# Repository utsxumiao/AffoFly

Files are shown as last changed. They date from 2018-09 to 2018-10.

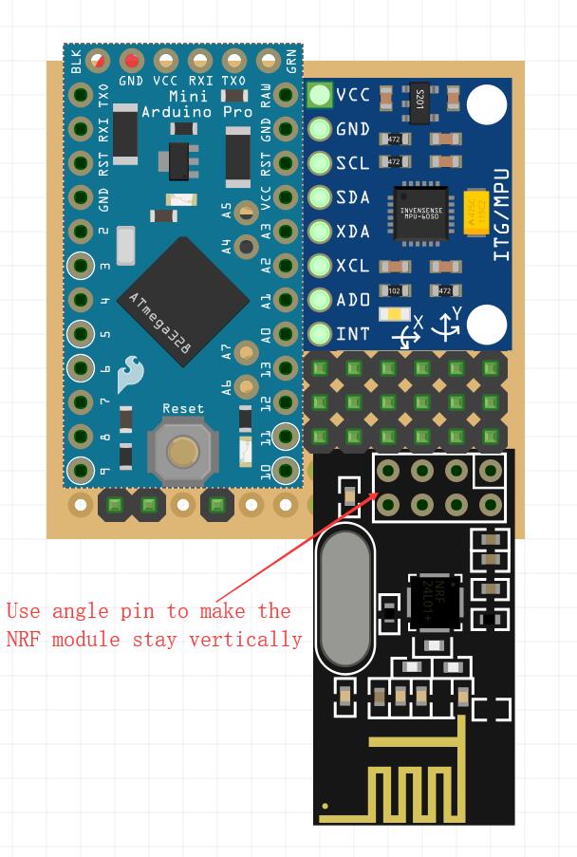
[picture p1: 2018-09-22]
Content/Images/AffoFly_MultiWii_Board_Layout_02.jpg

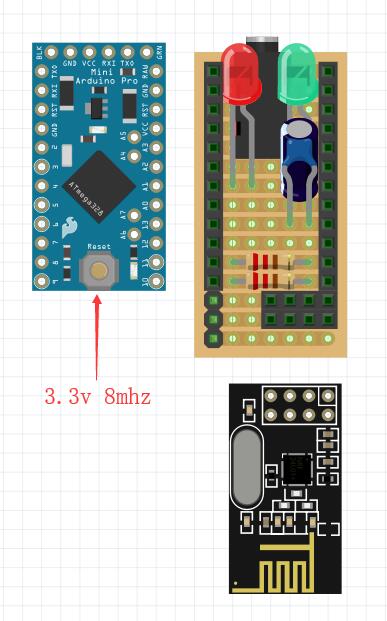
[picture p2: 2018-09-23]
Content/Images/AffoFly_Receiver_Board_Layout_01.jpg

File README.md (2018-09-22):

# AffoFly
Affordable Drone Project

### Warning
This software is experimental and a work in progress, it is partially developed at the moment and has not been tested in field yet. Code should be only used for reference until I feel comfortable to make it as a release version. DRONE CAN BE VERY DANGEROUS SO REMOVE YOUR PROPELLER!

THE SOFTWARE IS PROVIDED "AS IS", WITHOUT WARRANTY OF ANY KIND, EXPRESS OR IMPLIED, INCLUDING BUT NOT LIMITED TO THE WARRANTIES OF MERCHANTABILITY, FITNESS FOR A PARTICULAR PURPOSE AND NONINFRINGEMENT. IN NO EVENT SHALL THE AUTHORS OR COPYRIGHT HOLDERS BE LIABLE FOR ANY CLAIM, DAMAGES OR OTHER LIABILITY, WHETHER IN AN ACTION OF CONTRACT, TORT OR OTHERWISE, ARISING FROM, OUT OF OR IN CONNECTION WITH THE SOFTWARE OR THE USE OR OTHER DEALINGS IN THE SOFTWARE.

### What Is This Project About?
This is a complete **LOW COST** guide for DIY Arduino and NRF2401+ based drone package which includes: 
- Transmitter(TX): [AffoFly_Transmitter](/AffoFly_Transmitter)
- Receiver(RX): [AffoFly_Receiver](/AffoFly_Receiver)
- Flight Controller(FC): [AffoFly_MultiWii](/AffoFly_MultiWii)
- [Frame](/frame) (the body of drone) 
- [Other Parts](/other-parts) Brushless motors, Escs, batteries, propellers and so forth.

### The Motivation
I've been in RC hobby for about three years so far, mainly on building and flying drones and some glider planes. I've been seeing friends, neighbours, and sometimes, boys in the park shown great interest about DIY RC hobby, most of them played toy drones and wanna go deeper into DIY. Then they are scared away or stepped back after asking how much it will cost to enter DIY RC world (they actually meant the whole set to fly), a basic radio transmitter/receiver set already cost at least $50 as least. 

Products on shelf are normally over priced in Australia IMO and only good for urgent needs or "other good reasons", understandablly, labour and shipping cost is quite high here and the tiny market makes the case even worse, vendors only stock high value (of course better quality and better performance) items in order to maintain an acceptable margin. I do not against high end products as I do own some decent drone parts, transmitters and have been spending thousands over these years but that is not the topic of this project.

I was wondering if there is any way to let those guys try out in the pool before jumping into the ocean. Until recently I dive into [MultiWii](https://github.com/multiwii) and [Arduino](https://www.arduino.cc), I realised that it is absolutely possible to build the whole lot within $50 and they are hobby grade rather than just a ready made toy.

### The Goal
The aim of this project is mainly for people want try out DIY RC Drone without making too much damage to their bank account, ultimately get your DIY drone in the air under **$50**(USD). Also for learning purposes I would like to learn together on hardware and C/C++ programming as I am new to this as well. We are not going to reinvention the wheel if any aspect of this project has been done by someone, we are here to put them in use and improve it if possible.

### Prerequisites
To build a drone by following this project DOES NOT require expirence of software programming, just some simple configuration by instruction then upload the sketch onto your board and it should work, of course you do need to do some soldering work and some tools like soldering iron for those electronics parts and some handy work on the drone frame. 

### Welcome
If you would like to learn Arduino development, let's learn together! If you are a C/C++ programmer, it would be really appreciated if you can comment/help on improving this project, especially on my newbie's sketches. (I am a .NET developer have no background of hardware (C/C++) programming at all, sketches in this project are "working" but I am pretty sure there are many places could be better, eg. data types, workflows on handling loops...)

### Side Notes
 - **Radio Frequency**. The NRF24L01+ module provides 126 channels (0 - 125) mapping frequencies from 2400mhz to 2525mhz respectively, if you are planning to use it in areas close to residential like even indoor (a lot of WIFI) better stick to channels from 85 (2485mhz) and above to minimize interference, it gives you 40 channels to choose from, for simplicity I prefer starts from 100 and 25 channels is plenty for me. According to [List of WLAN channels](https://en.wikipedia.org/wiki/List_of_WLAN_channels) most WIFI routers are using frenquency under 2484mhz.

### Acknowlegements
- [MultiWii Community](http://www.multiwii.com)
- [Arduino](https://www.arduino.cc)
- [iforce2d](https://www.youtube.com/channel/UCTXOorupCLqqQifs2jbz7rQ). He has heaps of interesting, informative and yet good quality videos.

### Licensing
[MIT License](/LICENSE)

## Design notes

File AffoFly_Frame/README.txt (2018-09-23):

Here should contain all kinds of frame build, one frame per directory.

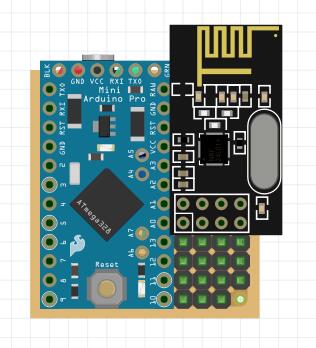
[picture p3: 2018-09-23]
Content/Images/AffoFly_Receiver_Board_Layout_04.jpg

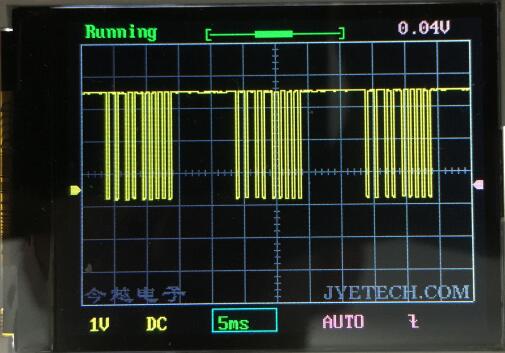
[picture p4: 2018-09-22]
Content/Images/Flysky_I6_PPM_5ms.jpg

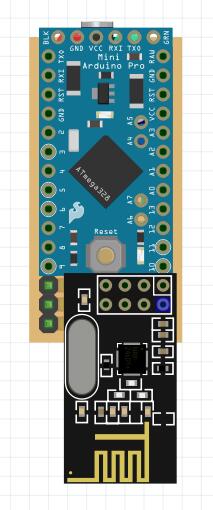
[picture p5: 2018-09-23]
Content/Images/AffoFly_Receiver_Board_Layout_02.jpg

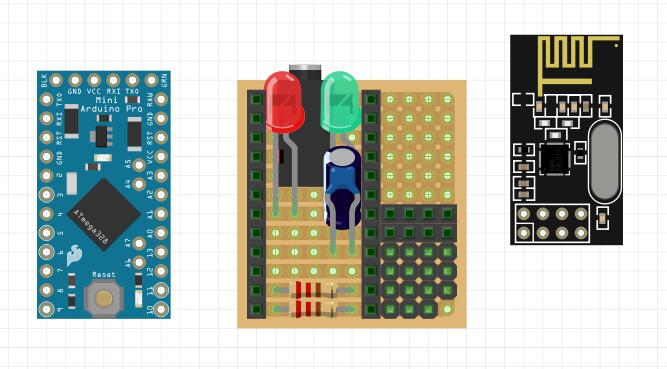
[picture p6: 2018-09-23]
Content/Images/AffoFly_Receiver_Board_Layout_03.jpg

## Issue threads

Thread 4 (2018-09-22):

Make TX output PPM signal for flight simulator

utsxumiao, 2018-09-22:
Currently I run out of PINs on TX Arduino.

Joysticks => A0, A1, A2, A3
Screen    => A4, A5
Battery   => A6
Dail (Aux6) => A7
Aux1-Aux5 buttons => 2, 3, 4, 5, 6
NRF24    => 7, 8, 11, 12, 13
Buzzer    => 9
Menu button => 10

I am wondering if I can use a pin currently for NRF module, keep NRF module connected but just not run radio function when TX is in simulator mode...... Need some investigation and tests.

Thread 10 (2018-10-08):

Button trigger multiple times in Control mode

utsxumiao, 2018-10-08:
This is something wrong in Control mode, when press buttons it triggers multiple times. This only happens in Control mode but working well in Function mode.

Not sure what is the cause but Arduino Studio does give low memory warning, code needs to be refactored to shrink size and improve performance.

utsxumiao, 2018-10-08:
Fixed in commit ffd4ae650dcb241efc1d0839de9541dfe30fbb60

Closed 2018-10-08.

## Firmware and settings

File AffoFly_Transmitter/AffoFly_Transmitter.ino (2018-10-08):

#include <EEPROM.h>
#include <SPI.h>
#include <Wire.h>
#include <nRF24L01.h>
#include <RF24.h>
#include <Bounce2.h>
#include <U8g2lib.h>
#include "printf.h"

//==== System Setting =============================================//
#define VERSION_NUMBER     "0.013"
//#define DEBUG_MODE  1
#define SHOW_RATE   1
//=======================================================================//

//==== Pin Definition ===================================================//
// PIN A4, A5 are used as I2C to connect LCD screen
// Pin 11, 12, 13 are used as SPI to connect NRF module
// Becareful: when use A6, A7 pin
//      A6, A7 are analog input only, also have no internal pullup.
//      You will need to add external pullup/pulldown resistor for them.
#define THROTTLE_PIN  A0
#define YAW_PIN       A1
#define PITCH_PIN     A2
#define ROLL_PIN      A3
#define V_BATTERY_PIN A6
#define AUX6_PIN      A7  //SWD
#define AUX1_PIN      2   //Arm - 2 states (bool)                                             //Menu: Save
#define AUX2_PIN      3   //Flight Mode - 3 states but could be more (byte: Acro/Angle/...)   //Menu: Up
#define AUX3_PIN      4   //Bomb Drop - 2 states (bool)                                       //Menu: Down
#define AUX4_PIN      5   //Beacon - 2 state (bool)                                           
#define AUX5_PIN      6   //
#define NRF_CE_PIN    7
#define NRF_CSN_PIN   8
#define BUZZER_PIN    9   //OUTPUT                                                            
#define MENU_PIN      10
//=======================================================================//

//==== Global Constant & Variable =======================================//
uint16_t BatteryVoltage = 0;
uint16_t LowBatteryVoltageThreshold = 3400; // mV

#ifdef SHOW_RATE
uint8_t SendRate = 0;
uint16_t LoopRate = 0;
uint8_t SendCount = 0;
uint16_t LoopCount = 0;
#endif

bool FunctionMode = false;
bool TrimmingMode = false;

const uint8_t RADIO_UNIQUE_ID_EEPROM_ADDRESS = 0; //(2 bytes 0-1)
const uint16_t RADIO_UNIQUE_ID_LOWER_BOUNDARY = 1000;
const uint16_t RADIO_UNIQUE_ID_UPPER_BOUNDARY = 9999;
uint16_t RadioUniqueId = RADIO_UNIQUE_ID_LOWER_BOUNDARY;

const uint8_t RADIO_PA_LEVEL_INDEX_EEPROM_ADDRESS = 4;
const uint8_t RADIO_PA_LEVEL_INDEX_LOWER_BOUNDARY = 0; //RF24_PA_MIN, RF24_PA_LOW, RF24_PA_HIGH, RF24_PA_MAX
const uint8_t RADIO_PA_LEVEL_INDEX_UPPER_BOUNDARY = 3; //TODO: use index instead
int8_t RadioPaLevelIndex = 3;

const uint8_t CURRENT_RX_ID_EEPROM_ADDRESS = 5; //TODO: Implement Multiple RX support
const uint8_t CURRENT_RX_ID_LOWER_BOUNDARY = 1;
const uint8_t CURRENT_RX_ID_UPPER_BOUNDARY = 10;
uint8_t CurrentRxId = 1;

const uint8_t RX_CONFIG_EEPROM_START_ADDRESS = 100;
const uint8_t RX_CONFIG_ALLOCATED_BYTES = 20;
const uint8_t RX_TRIM_STEP_RANGE = 15;
const uint8_t RX_TRIM_STEP_WIDTH = 2;

const uint8_t RADIO_CHANNEL_LOWER_BOUNDARY = 100;
const uint8_t RADIO_CHANNEL_UPPER_BOUNDARY = 125;
const uint64_t RADIO_PIPE_OUT = 0xE8E8F0F0E1LL;
RF24 radio(NRF_CE_PIN, NRF_CSN_PIN);

U8G2_SSD1306_128X64_NONAME_2_HW_I2C u8g2(U8G2_R0, /* clock=*/ SCL, /* data=*/ SDA, /* reset=*/ U8X8_PIN_NONE);

const uint8_t AUX1_VALUE_LOWER_BOUNDARY = 0;
const uint8_t AUX1_VALUE_UPPER_BOUNDARY = 1;
uint8_t Aux1Value = AUX1_VALUE_LOWER_BOUNDARY;
Bounce Aux1Bounce = Bounce();
bool Aux1Pressed = false;
const uint8_t AUX2_VALUE_LOWER_BOUNDARY = 0;
const uint8_t AUX2_VALUE_UPPER_BOUNDARY = 2;
uint8_t Aux2Value = AUX2_VALUE_LOWER_BOUNDARY;
Bounce Aux2Bounce = Bounce();
bool Aux2Pressed = false;
const uint8_t AUX3_VALUE_LOWER_BOUNDARY = 0;
const uint8_t AUX3_VALUE_UPPER_BOUNDARY = 1;
uint8_t Aux3Value = AUX3_VALUE_LOWER_BOUNDARY;
Bounce Aux3Bounce = Bounce();
bool Aux3Pressed = false;
const uint8_t AUX4_VALUE_LOWER_BOUNDARY = 0;
const uint8_t AUX4_VALUE_UPPER_BOUNDARY = 1;
uint8_t Aux4Value = AUX4_VALUE_LOWER_BOUNDARY;
Bounce Aux4Bounce = Bounce();
bool Aux4Pressed = false;
const uint8_t AUX5_VALUE_LOWER_BOUNDARY = 0;
const uint8_t AUX5_VALUE_UPPER_BOUNDARY = 3;
uint8_t Aux5Value = AUX5_VALUE_LOWER_BOUNDARY;
Bounce Aux5Bounce = Bounce();
bool Aux5Pressed = false;

Bounce MenuBounce = Bounce();
bool MenuPressed = false;

// NRF24L01+ module can send maximum 32 byte per package
struct MyData {
  uint16_t UniqueId;
  uint16_t Throttle;
  uint16_t Yaw;
  uint16_t Pitch;
  uint16_t Roll;
  uint16_t Aux1;
  uint16_t Aux2;
  uint16_t Aux3;
  uint16_t Aux4;
  uint16_t Aux5;
  uint16_t Aux6;
};
MyData data;

const uint16_t BatteryVoltageReadInterval = 10000;
unsigned long BatteryVoltageReadLastMillis = 0;

const uint16_t FunctionWelcomeScreenShowDuration = 2000;

const uint16_t TimerRefreshInterval = 1000;
unsigned long TimerRefreshLastMillis = 0;
uint16_t Timer_Seconds = 0;

uint16_t ScreenRefreshInterval = 500;
unsigned long ScreenRefreshLastMillis = 0;

bool BuzzerEnabled = false;
uint8_t BuzzerTimesToBeep = 0;
byte BuzzerState = LOW;
uint16_t BuzzerBeepInterval = 50;
unsigned long BuzzerBeepLastMillis = 0;

const uint8_t RadioSendInterval = 10;
unsigned long RadioSendLastMillis = 0;

char FlightMode[3][10] = {
  "ACRO",
  "ANGLE",
  "HORIZON"
};

// RxConfig data limit is 20 bytes
// We allocates 10 RxConfig in EEPROM from address 100 to 299
struct RxConfigData {
  uint8_t Id;
  uint8_t RadioChannel;
  int8_t ThrottleTrim;
  int8_t YawTrim;
  int8_t PitchTrim;
  int8_t RollTrim;
  char Name[10];
};

RxConfigData rxConfig;
RxConfigData RxConfigs[10];

struct RadioPaLevelData {
  uint8_t PaValue;
  char PaName[5];
};

RadioPaLevelData RadioPaLevels[4] = {
  {RF24_PA_MIN, "MIN"},
  {RF24_PA_LOW, "LOW"},
  {RF24_PA_HIGH, "HIGH"},
  {RF24_PA_MAX, "MAX"}
};

char Functions[4][15] = {
  "Transmitter ID",
  "Radio PA Level",
  "RX Selection",
  "Wipe All Data"
};

uint8_t CurrentTrimmingIndex = 0; // 0=>Yaw, 1=>Throttle, 2=>Pitch, 3=>Roll
uint8_t CurrentFunctionIndex = 0;
uint8_t SelectedFunctionIndex = 1;
uint8_t SelectedRxId = CurrentRxId;
uint8_t RxConfigurationIndex = 0;
uint8_t RxConfigurationNameIndex = 0;
char RxConfigurationName[10] = "";
uint8_t RxConfigurationChannel = 100;

//=======================================================================//

void setup() {
#ifdef DEBUG_MODE
  Serial.begin(115200);
#endif
  u8g2.begin();
  u8g2.setFont(u8g2_font_profont12_tr);
  readEeprom();
  pinMode(AUX1_PIN, INPUT_PULLUP);
  pinMode(AUX2_PIN, INPUT_PULLUP);
  pinMode(AUX3_PIN, INPUT_PULLUP);
  pinMode(AUX4_PIN, INPUT_PULLUP);
  pinMode(AUX5_PIN, INPUT_PULLUP);
  pinMode(MENU_PIN, INPUT_PULLUP);
  pinMode(BUZZER_PIN, OUTPUT);

  Aux1Bounce.attach(AUX1_PIN);
  Aux2Bounce.attach(AUX2_PIN);
  Aux3Bounce.attach(AUX3_PIN);
  Aux4Bounce.attach(AUX4_PIN);
  Aux5Bounce.attach(AUX5_PIN);
  MenuBounce.attach(MENU_PIN);
  Aux1Bounce.interval(5);
  Aux2Bounce.interval(5);
  Aux3Bounce.interval(5);
  Aux4Bounce.interval(5);
  Aux5Bounce.interval(5);
  MenuBounce.interval(5);

  MenuBounce.update();
  if (MenuBounce.read() == LOW) {
    FunctionMode = true;
    ScreenRefreshInterval = 200;
    BuzzerTimesToBeep = 3;
  } else {
    FunctionMode = false;
    BuzzerTimesToBeep = 1;
  }

  // Seed RxConfigs if it does not already exist
  if (EEPROM.read(RX_CONFIG_EEPROM_START_ADDRESS) == 0) {
#ifdef DEBUG_MODE
    Serial.println("RX data does not exist, seed data.");
#endif
    putRxConfigs();
  }

  //FunctionMode = true; //For testing only, remove after.

  if (FunctionMode) {
    drawFunctionWelcomeScreen();
    getRxConfigs();
#ifdef DEBUG_MODE
    dumpEeprom();
#endif
  } else {
    rxConfig = getRxConfig(CurrentRxId);
    radio.begin();
    radio.setPALevel(RadioPaLevels[RadioPaLevelIndex].PaValue);
    radio.setAutoAck(false);
    radio.setChannel(rxConfig.RadioChannel);
    radio.setDataRate(RF24_250KBPS);
    radio.openWritingPipe(RADIO_PIPE_OUT);
    radio.startListening();
    radio.stopListening();
#ifdef DEBUG_MODE
    printf_begin();
    radio.printDetails();
    Serial.print("UniqueId "); Serial.print(RadioUniqueId);
    Serial.print("    Channel "); Serial.println(rxConfig.RadioChannel);
#endif
  }
  resetData();
  readBatteryVoltage(10001); //Dummy value > BatteryVoltageReadInterval to force battery read once
}

void loop() {
  unsigned long currentMillis = millis();
  if (FunctionMode) {
    if (currentMillis > FunctionWelcomeScreenShowDuration) {
      setTime(currentMillis);
      setFunctionValues();
      beepBuzzer(currentMillis);
      refreshFunctionOperationScreen(currentMillis);
    }
  } else {
    readBatteryVoltage(currentMillis);
    setTime(currentMillis);
    setButtonsValue(currentMillis);
    beepBuzzer(currentMillis);
    sendPayloadData(currentMillis);
    refreshControlScreen(currentMillis);
  }
#ifdef SHOW_RATE
  LoopCount++;
#endif
}

void readEeprom() {
  EEPROM.get(RADIO_UNIQUE_ID_EEPROM_ADDRESS, RadioUniqueId);
  if (RadioUniqueId < RADIO_UNIQUE_ID_LOWER_BOUNDARY || RadioUniqueId > RADIO_UNIQUE_ID_UPPER_BOUNDARY) {
    RadioUniqueId = RADIO_UNIQUE_ID_LOWER_BOUNDARY;
    EEPROM.write(RADIO_UNIQUE_ID_EEPROM_ADDRESS, RadioUniqueId);
  }

  RadioPaLevelIndex = EEPROM.read(RADIO_PA_LEVEL_INDEX_EEPROM_ADDRESS);
  if (RadioPaLevelIndex < RADIO_PA_LEVEL_INDEX_LOWER_BOUNDARY || RadioPaLevelIndex > RADIO_PA_LEVEL_INDEX_UPPER_BOUNDARY) {
    RadioPaLevelIndex = RADIO_PA_LEVEL_INDEX_UPPER_BOUNDARY;
    EEPROM.write(RADIO_PA_LEVEL_INDEX_EEPROM_ADDRESS, RadioPaLevelIndex);
  }

  CurrentRxId = EEPROM.read(CURRENT_RX_ID_EEPROM_ADDRESS);
  if (CurrentRxId < CURRENT_RX_ID_LOWER_BOUNDARY || CurrentRxId > CURRENT_RX_ID_UPPER_BOUNDARY) {
    CurrentRxId = CURRENT_RX_ID_LOWER_BOUNDARY;
    EEPROM.write(CURRENT_RX_ID_EEPROM_ADDRESS, CurrentRxId);
  }
}

void putRxConfigs() {
  for (int i = CURRENT_RX_ID_LOWER_BOUNDARY; i <= CURRENT_RX_ID_UPPER_BOUNDARY; i++) {
    uint16_t startAddress = (uint16_t)RX_CONFIG_ALLOCATED_BYTES * (i - 1) + RX_CONFIG_EEPROM_START_ADDRESS;
    RxConfigData rxConfig;
    rxConfig.Id = i;
    rxConfig.RadioChannel = 100;
    rxConfig.ThrottleTrim = 0;
    rxConfig.YawTrim = 0;
    rxConfig.PitchTrim = 0;
    rxConfig.RollTrim = 0;
    char rxName[10] = "RX ";
    char rxIdText[3] = "";
    itoa(i, rxIdText, 10);
    if (i < 10) {
      strcat(rxName, "0");
    }
    strcat(rxName, rxIdText);
    strcat(rxName, "    ");
    strcpy(rxConfig.Name, rxName);
    EEPROM.put(startAddress, rxConfig);
  }
}

void getRxConfigs() {
  for (int i = CURRENT_RX_ID_LOWER_BOUNDARY; i <= CURRENT_RX_ID_UPPER_BOUNDARY; i++) {
    uint16_t startAddress = (uint16_t)RX_CONFIG_ALLOCATED_BYTES * (i - 1) + RX_CONFIG_EEPROM_START_ADDRESS;
    RxConfigData rxConfig;
    EEPROM.get(startAddress, rxConfig);
    RxConfigs[i - 1] = rxConfig;
  }
}

RxConfigData getRxConfig(uint8_t rxId) {
  uint16_t address = (uint16_t)RX_CONFIG_ALLOCATED_BYTES * (rxId - 1) + RX_CONFIG_EEPROM_START_ADDRESS;
  RxConfigData rxConfig;
  EEPROM.get(address, rxConfig);
  return rxConfig;
}

void clearEeprom() {
  for (int i = 0 ; i < EEPROM.length() ; i++) {
    EEPROM.update(i, 0);
  }
  softReset();
}

void setFunctionValues() {
  Aux1Bounce.update();
  Aux2Bounce.update();
  Aux3Bounce.update();
  Aux4Bounce.update();
  Aux5Bounce.update();
  MenuBounce.update();
  int pressedButtonIndex = -1;

  if (MenuBounce.read() == LOW) {
    if (!MenuPressed) {
      MenuPressed = true;
      pressedButtonIndex = 0;
      BuzzerTimesToBeep = 1;
    }
  } else {
    MenuPressed = false;
  }
  if (Aux1Bounce.read() == LOW) {
    if (!Aux1Pressed) {
      Aux1Pressed = true;
      pressedButtonIndex = 2;
      BuzzerTimesToBeep = 1;
    }
  } else {
    Aux1Pressed = false;
  }
  if (Aux4Bounce.read() == LOW) {
    if (!Aux4Pressed) {
      Aux4Pressed = true;
      pressedButtonIndex = 1;
      BuzzerTimesToBeep = 1;
    }
  } else {
    Aux4Pressed = false;
  }
  if (Aux5Bounce.read() == LOW) {
    if (!Aux5Pressed) {
      Aux5Pressed = true;
      pressedButtonIndex = 3;
      BuzzerTimesToBeep = 1;
    }
  } else {
    Aux5Pressed = false;
  }
  if (Aux3Bounce.read() == LOW) {
    if (!Aux3Pressed) {
      Aux3Pressed = true;
      pressedButtonIndex = 4;
      BuzzerTimesToBeep = 1;
    }
  } else {
    Aux3Pressed = false;
  }

  if (pressedButtonIndex > -1) {
    if (CurrentFunctionIndex == 0) {
      //Currently at Main Menu
      switch (pressedButtonIndex) {
        case 0: //Cancel
          break;
        case 1: //Confirm
          CurrentFunctionIndex = SelectedFunctionIndex;
          readEeprom();
          break;
        case 2: //Up
          SelectedFunctionIndex--;
          break;
        case 3: //Down
          SelectedFunctionIndex++;
          break;
      }
      uint8_t functionCount = sizeof(Functions) / sizeof(Functions[0]);
      if (SelectedFunctionIndex > functionCount) SelectedFunctionIndex = 1;
      if (SelectedFunctionIndex < 1) SelectedFunctionIndex = functionCount;
    }
    else if (CurrentFunctionIndex == 1) {
      //Currently at Transmitter Id function
      switch (pressedButtonIndex) {
        case 0: //Cancel
          CurrentFunctionIndex = 0;
          break;
        case 1: //Confirm
          EEPROM.put(RADIO_UNIQUE_ID_EEPROM_ADDRESS, RadioUniqueId);
          break;
        case 2: //Up
          RadioUniqueId++;
          break;
        case 3: //Down
          RadioUniqueId--;
          break;
          //case 4: //Move Position TODO: make it easier to change value by each digit
      }
      if (RadioUniqueId < RADIO_UNIQUE_ID_LOWER_BOUNDARY) RadioUniqueId = RADIO_UNIQUE_ID_UPPER_BOUNDARY;
      if (RadioUniqueId > RADIO_UNIQUE_ID_UPPER_BOUNDARY) RadioUniqueId = RADIO_UNIQUE_ID_LOWER_BOUNDARY;
    }
    else if (CurrentFunctionIndex == 2) {
      //Currently at Radio PA Level function
      switch (pressedButtonIndex) {
        case 0: //Cancel
          CurrentFunctionIndex = 0;
          break;
        case 1: //Confirm
          EEPROM.update(RADIO_PA_LEVEL_INDEX_EEPROM_ADDRESS, RadioPaLevelIndex);
          break;
        case 2: //Up
          RadioPaLevelIndex++;
          break;
        case 3: //Down
          RadioPaLevelIndex--;
          break;
      }
      if (RadioPaLevelIndex < RADIO_PA_LEVEL_INDEX_LOWER_BOUNDARY) RadioPaLevelIndex = RADIO_PA_LEVEL_INDEX_UPPER_BOUNDARY;
      if (RadioPaLevelIndex > RADIO_PA_LEVEL_INDEX_UPPER_BOUNDARY) RadioPaLevelIndex = RADIO_PA_LEVEL_INDEX_LOWER_BOUNDARY;
    }
    else if (CurrentFunctionIndex == 3) {
      //Currently at RX Selection function
      switch (pressedButtonIndex) {
        case 0: //Cancel
          SelectedRxId = CurrentRxId;
          CurrentFunctionIndex = 0;
          break;
        case 1: //Confirm
#ifdef DEBUG_MODE
          Serial.print("SelectedRxId: "); Serial.println(SelectedRxId);
#endif
          CurrentRxId = SelectedRxId;
          EEPROM.update(CURRENT_RX_ID_EEPROM_ADDRESS, CurrentRxId);
          strcpy(RxConfigurationName, RxConfigs[CurrentRxId - 1].Name);
          RxConfigurationChannel = RxConfigs[CurrentRxId - 1].RadioChannel;
          RxConfigurationIndex = 0;
          RxConfigurationNameIndex = 0;
          CurrentFunctionIndex = 10; // 10 for RX Configuration function
          break;
        case 2: //Up
          SelectedRxId--;
          break;
        case 3: //Down
          SelectedRxId++;
          break;
      }
      if (SelectedRxId < CURRENT_RX_ID_LOWER_BOUNDARY) SelectedRxId = CURRENT_RX_ID_UPPER_BOUNDARY;
      if (SelectedRxId > CURRENT_RX_ID_UPPER_BOUNDARY) SelectedRxId = CURRENT_RX_ID_LOWER_BOUNDARY;
    }
    else if (CurrentFunctionIndex == 4) {
      //Currently at Wipe All Data function
      switch (pressedButtonIndex) {
        case 0: //Cancel
          CurrentFunctionIndex = 0;
          break;
        case 1: //Confirm
          clearEeprom();
          break;
      }
    }
    else if (CurrentFunctionIndex == 10) {
      //Currently at RX Configuration function
      switch (pressedButtonIndex) {
        case 0: //Cancel
          CurrentFunctionIndex = 0;
          break;
        case 1: //Confirm
          strcpy(RxConfigs[CurrentRxId - 1].Name, RxConfigurationName);
          RxConfigs[CurrentRxId - 1].RadioChannel = RxConfigurationChannel;
          EEPROM.put(RX_CONFIG_EEPROM_START_ADDRESS + (CurrentRxId - 1) * RX_CONFIG_ALLOCATED_BYTES, RxConfigs[CurrentRxId - 1]);
          break;
        case 2: //Up
          switch (RxConfigurationIndex) {
            case 0: //RX Name
              RxConfigurationName[RxConfigurationNameIndex] -= 1;
              if (RxConfigurationName[RxConfigurationNameIndex] < 32) RxConfigurationName[RxConfigurationNameIndex] = 126;
              break;
            case 1: //RX Channel
              RxConfigurationChannel++;
              if (RxConfigurationChannel > RADIO_CHANNEL_UPPER_BOUNDARY) RxConfigurationChannel = RADIO_CHANNEL_LOWER_BOUNDARY;
          }
          break;
        case 3: //Down
          switch (RxConfigurationIndex) {
            case 0: //RX Name
#ifdef DEBUG_MODE
              Serial.println(RxConfigurationName);
#endif
              RxConfigurationName[RxConfigurationNameIndex] += 1;
              if (RxConfigurationName[RxConfigurationNameIndex] > 126) RxConfigurationName[RxConfigurationNameIndex] = 32;
#ifdef DEBUG_MODE
              Serial.println(RxConfigurationName);
#endif
              break;
            case 1: //RX Channel
              RxConfigurationChannel--;
              if (RxConfigurationChannel < RADIO_CHANNEL_LOWER_BOUNDARY) RxConfigurationChannel = RADIO_CHANNEL_UPPER_BOUNDARY;
          }
          break;
        case 4: //Move Position
          if (RxConfigurationIndex == 0) {
            RxConfigurationNameIndex++;
            if (RxConfigurationNameIndex > 8) { //TODO: Make it globle variable
              RxConfigurationNameIndex = 0;
              RxConfigurationIndex = 1;
            }
          } else {
            RxConfigurationIndex = 0;
          }
          break;
      }
    }
    else {
      //Other function
    }
  }
}

void setTime(unsigned long currentMillis) {
  if (currentMillis - TimerRefreshLastMillis >= TimerRefreshInterval) {
    TimerRefreshLastMillis = currentMillis;
    if (Aux1Value > 0)
      Timer_Seconds++;
    else
      Timer_Seconds = 0;
#ifdef SHOW_RATE
    SendRate = SendCount;
    LoopRate = LoopCount;
    SendCount = 0;
    LoopCount = 0;
#endif
  }
}

void resetData() {
  //Value 1000 - 2000, 1500 is middle/neutral
  data.Throttle = 1000;
  data.Yaw = 1500;
  data.Pitch = 1500;
  data.Roll = 1500;
  data.Aux1 = 1000;
  data.Aux2 = 1000;
  data.Aux3 = 1000;
  data.Aux4 = 1000;
  data.Aux5 = 1000;
  data.Aux6 = 1000;
}

uint16_t mapJoystickValues(uint16_t val, uint16_t lower, uint16_t middle, uint16_t upper, bool reverse) {
  val = constrain(val, lower, upper);
  if (val < middle) val = map(val, lower, middle, 1000, 1500);
  else val = map(val, middle, upper, 1500, 2000);
  return reverse ? 3000 - val : val;
}

void setButtonsValue(unsigned long currentMillis) {
  Aux1Bounce.update();
  Aux2Bounce.update();
  Aux3Bounce.update();
  Aux4Bounce.update();
  Aux5Bounce.update();
  MenuBounce.update();

  if (Aux1Bounce.read() == LOW) {
    if (!Aux1Pressed) {
      if (TrimmingMode) {
#ifdef DEBUG_MODE
        Serial.println("Current RX config data: ");
        Serial.print("Id=>");
        Serial.print(rxConfig.Id);
        Serial.print("  Name=>");
        Serial.print(rxConfig.Name);
        Serial.print("  RadioChannel=>");
        Serial.print(rxConfig.RadioChannel);
        Serial.print("  YawTrim=>");
        Serial.print(rxConfig.YawTrim);
        Serial.print("  ThrottleTrim=>");
        Serial.print(rxConfig.ThrottleTrim);
        Serial.print("  PitchTrim=>");
        Serial.print(rxConfig.PitchTrim);
        Serial.print("  RollTrim=>");
        Serial.print(rxConfig.RollTrim);
        Serial.println("");
#endif
        switch (CurrentTrimmingIndex) {
          case 0: //Yaw
            rxConfig.YawTrim++;
            if (rxConfig.YawTrim > RX_TRIM_STEP_RANGE) {
              rxConfig.YawTrim = RX_TRIM_STEP_RANGE;
            }
            if (rxConfig.YawTrim == 0) BuzzerTimesToBeep = 3;
            else BuzzerTimesToBeep = 1;
            break;
          case 1: //Throttle
            rxConfig.ThrottleTrim++;
            if (rxConfig.ThrottleTrim >= RX_TRIM_STEP_RANGE) {
              rxConfig.ThrottleTrim = RX_TRIM_STEP_RANGE;
            }
            if (rxConfig.ThrottleTrim == 0) BuzzerTimesToBeep = 3;
            else BuzzerTimesToBeep = 1;
            break;
          case 2: //Pitch
            rxConfig.PitchTrim++;
            if (rxConfig.PitchTrim >= RX_TRIM_STEP_RANGE) {
              rxConfig.PitchTrim = RX_TRIM_STEP_RANGE;
            }
            if (rxConfig.PitchTrim == 0) BuzzerTimesToBeep = 3;
            else BuzzerTimesToBeep = 1;
            break;
          case 3: //Roll
            rxConfig.RollTrim++;
            if (rxConfig.RollTrim >= RX_TRIM_STEP_RANGE) {
              rxConfig.RollTrim = RX_TRIM_STEP_RANGE;
            }
            if (rxConfig.RollTrim == 0) BuzzerTimesToBeep = 3;
            else BuzzerTimesToBeep = 1;
            break;
        }
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

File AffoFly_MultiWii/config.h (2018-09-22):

#ifndef CONFIG_H_
#define CONFIG_H_

/*************************************************************************************************/
/****           CONFIGURABLE PARAMETERS                                                       ****/
/*************************************************************************************************/

/* this file consists of several sections
 * to create a working combination you must at least make your choices in section 1.
 * 1 - BASIC SETUP - you must select an option in every block.
 *      this assumes you have 4 channels connected to your board with standard ESCs and servos.
 * 2 - COPTER TYPE SPECIFIC OPTIONS - you likely want to check for options for your copter type
 * 3 - RC SYSTEM SETUP
 * 4 - ALTERNATE CPUs & BOARDS - if you have
 * 5 - ALTERNATE SETUP - select alternate RX (SBUS, PPM, etc.), alternate ESC-range, etc. here
 * 6 - OPTIONAL FEATURES - enable nice to have features here (FlightModes, LCD, telemetry, battery monitor etc.)
 * 7 - TUNING & DEVELOPER - if you know what you are doing; you have been warned
 *     - (ESCs calibration, Dynamic Motor/Prop Balancing, Diagnostics,Memory savings.....)
 * 8 - DEPRECATED - these features will be removed in some future release
 */

/* Notes:
 * 1. parameters marked with (*) in the comment are stored in eeprom and can be changed via serial monitor or LCD.
 * 2. parameters marked with (**) in the comment are stored in eeprom and can be changed via the GUI
 */


/*************************************************************************************************/
/*****************                                                                 ***************/
/****************  SECTION  1 - BASIC SETUP                                                *******/
/*****************                                                                 ***************/
/*************************************************************************************************/

  /**************************    The type of multicopter    ****************************/
    //#define GIMBAL
    //#define BI
    //#define TRI
    //#define QUADP
    #define QUADX
    //#define Y4
    //#define Y6
    //#define HEX6
    //#define HEX6X
    //#define HEX6H  // New Model
    //#define OCTOX8
    //#define OCTOFLATP
    //#define OCTOFLATX
    //#define FLYING_WING
    //#define VTAIL4
    //#define AIRPLANE
    //#define SINGLECOPTER
    //#define DUALCOPTER
    //#define HELI_120_CCPM
    //#define HELI_90_DEG

  /****************************    Motor minthrottle    *******************************/
    /* Set the minimum throttle command sent to the ESC (Electronic Speed Controller)
       This is the minimum value that allow motors to run at a idle speed  */
    //#define MINTHROTTLE 1300 // for Turnigy Plush ESCs 10A
    //#define MINTHROTTLE 1120 // for Super Simple ESCs 10A
    //#define MINTHROTTLE 1064 // special ESC (simonk)
    //#define MINTHROTTLE 1050 // for brushed ESCs like ladybird
    #define MINTHROTTLE 1150 // (*) (**)

  /****************************    Motor maxthrottle    *******************************/
    /* this is the maximum value for the ESCs at full power, this value can be increased up to 2000 */
    #define MAXTHROTTLE 1850

  /****************************    Mincommand          *******************************/
    /* this is the value for the ESCs when they are not armed
       in some cases, this value must be lowered down to 900 for some specific ESCs, otherwise they failed to initiate */
    #define MINCOMMAND  1000

  /**********************************  I2C speed for old WMP config (useless config for other sensors)  *************/
    #define I2C_SPEED 100000L     //100kHz normal mode, this value must be used for a genuine WMP
    //#define I2C_SPEED 400000L   //400kHz fast mode, it works only with some WMP clones

  /***************************    Internal i2c Pullups   ********************************/
    /* enable internal I2C pull ups (in most cases it is better to use external pullups) */
    //#define INTERNAL_I2C_PULLUPS

  /**********************************  constant loop time  ******************************/
    #define LOOP_TIME 2800

  /**************************************************************************************/
  /*****************          boards and sensor definitions            ******************/
  /**************************************************************************************/
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

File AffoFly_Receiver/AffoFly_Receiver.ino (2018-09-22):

#include <EEPROM.h>
#include <SPI.h>
#include <nRF24L01.h>
#include <RF24.h>
#include "printf.h"

//==== System Setting =============================================//
#define VERSION_NUMBER     "0.012"
#define DEBUG_MODE  1
#define CLOCK_MULTIPLIER 1 // set this to 2 if you are using a 16MHz arduino, leave as 1 for an 8MHz arduino
//=======================================================================//

//==== Pin Definition ===================================================//
#define PPM_PIN       2 // It has to be 2 unless you also update setPPM() and ISR
#define BLUE_LED_PIN  3
#define RED_LED_PIN   4
#define NRF_CE_PIN    7
#define NRF_CSN_PIN   8
//=======================================================================//

//==== Global Constant & Variable =======================================//
const uint16_t PPM_FRAME_LENGTH = 24000;
const uint16_t PPM_PULSE_LENGTH = 400;
const uint8_t CHANNEL_COUNT = 10;
const uint16_t RADIO_TX_ID = 1005;
const uint16_t RADIO_RX_ID = 1;
const uint8_t RADIO_CHANNEL = 101;
const uint64_t RADIO_PIPE_OUT = 0xE8E8F0F0E1LL;

const uint16_t RADIO_SIGNAL_TIMEOUT = 500;
unsigned long RadioSignalLastMillis = 0;
const uint8_t LED_FLASH_INTERVAL = 20;
unsigned long LedFlashLastMillis = 0;
const uint16_t RATE_REFRESH_INTERVAL = 1000;
unsigned long RateRefreshLastMillis = 0;

bool HasSignal = false;
bool BlueLedState = false;
bool RedLedState = false;

RF24 radio(NRF_CE_PIN, NRF_CSN_PIN);

struct MyData {
  uint16_t TxId;
  //uint16_t RxId;
  uint16_t Throttle;
  uint16_t Yaw;
  uint16_t Pitch;
  uint16_t Roll;
  uint16_t Aux1;
  uint16_t Aux2;
  uint16_t Aux3;
  uint16_t Aux4;
  uint16_t Aux5;
  uint16_t Aux6;
};
MyData data;

uint16_t PPM[CHANNEL_COUNT];

#ifdef DEBUG_MODE
uint16_t PackageCount = 0;
uint16_t PackageRate = 0;
uint16_t LoopCount = 0;
uint16_t LoopRate = 0;
#endif
//=======================================================================//

void setup() {
#ifdef DEBUG_MODE
  Serial.begin(115200);
#endif
  pinMode(PPM_PIN, OUTPUT);
  pinMode(BLUE_LED_PIN, OUTPUT);
  pinMode(RED_LED_PIN, OUTPUT);

  radio.begin();
  radio.setPALevel(RF24_PA_MIN);
  radio.setChannel(RADIO_CHANNEL);
  radio.setDataRate(RF24_250KBPS);
  radio.setAutoAck(false);
  radio.openReadingPipe(1, RADIO_PIPE_OUT);
  radio.startListening();
#ifdef DEBUG_MODE
  printf_begin();
  radio.printDetails();
#endif

  setupPPM();
  resetData();
}

void loop() {
  unsigned long currentMillis = millis();
  receiveData(currentMillis);
  checkSignal(currentMillis);
  flashLed(currentMillis);
  LoopCount++;
  calculateRate(currentMillis);
}

void calculateRate(unsigned long currentMillis) {
  if (currentMillis - RateRefreshLastMillis >= RATE_REFRESH_INTERVAL) {
    RateRefreshLastMillis = currentMillis;
    PackageRate = PackageCount;
    LoopRate = LoopCount;
    PackageCount = 0;
    LoopCount = 0;
#ifdef DEBUG_MODE
    Serial.print(PackageRate);  Serial.print(" / ");  Serial.println(LoopRate);
#endif
  }
}

void receiveData(unsigned long currentMillis) {
  while(radio.available()){
    radio.read(&data, sizeof(MyData));
    if(data.TxId == RADIO_TX_ID) {
      HasSignal = true;
      RadioSignalLastMillis = currentMillis;
      PackageCount++;
#ifdef DEBUG_MODE
//      Serial.print("Data received at: ");  Serial.print(millis());  Serial.print("    "); 
#endif
      setPPMValuesFromData();
    }
#ifdef DEBUG_MODE
//    Serial.print("PPM output at: ");  Serial.println(millis());
//    Serial.print("TxId: "); Serial.print(data.TxId);  Serial.print("    ");
//    Serial.print("Throttle: "); Serial.print(data.Throttle);  Serial.print("    ");
//    Serial.print("Yaw: ");      Serial.print(data.Yaw);       Serial.print("    ");
//    Serial.print("Pitch: ");    Serial.print(data.Pitch);     Serial.print("    ");
//    Serial.print("Roll: ");     Serial.print(data.Roll);      Serial.print("    ");
//    Serial.print("Aux1: ");     Serial.print(data.Aux1);      Serial.print("    ");
//    Serial.print("Aux2: ");     Serial.print(data.Aux2);      Serial.print("    ");
//    Serial.print("Aux3: ");     Serial.print(data.Aux3);      Serial.print("    ");
//    Serial.print("Aux4: ");     Serial.print(data.Aux4);      Serial.print("    ");
//    Serial.print("Aux5: ");     Serial.print(data.Aux5);      Serial.print("    ");
//    Serial.print("Aux6: ");     Serial.print(data.Aux6);      Serial.print("\n");
#endif
  }
}

void checkSignal(unsigned long currentMillis) {
  if(currentMillis - RadioSignalLastMillis >= RADIO_SIGNAL_TIMEOUT) {
    HasSignal = false;
    resetData();
  }
}

// Given currently the AffoFly TX (with 8mhz) sends about 70 pps
// I consider 50 pps on FC/RX side is good enough
// PackageRate >= 50: Blue solid, Red off
// PackageRate >= 40: Blue flashing, Red off
// PackageRate >= 30: Blue flashing, Red flashing
// PackageRate < 30:  Blue off, Red solid
// No signal (500ms no package received): Blue off, Red off
void flashLed(unsigned long currentMillis) {
  if (currentMillis - LedFlashLastMillis >= LED_FLASH_INTERVAL) {
    LedFlashLastMillis = currentMillis;
    if (HasSignal) {
      if (PackageRate >= 50) {
        BlueLedState = true;
        RedLedState = false;
      } else if (PackageRate >= 40) {
        BlueLedState = !BlueLedState;
        RedLedState = false;
      } else if (PackageRate >= 30) {
        BlueLedState = !BlueLedState;
        RedLedState = !RedLedState;
      } else {
        BlueLedState = false;
        RedLedState = true;
      }
    } else {
      if (BlueLedState) BlueLedState = false;
      if (RedLedState) RedLedState = false;
    }
    digitalWrite(BLUE_LED_PIN, BlueLedState);
    digitalWrite(RED_LED_PIN, RedLedState);
  }
}

void resetData() {
  //Value 1000 - 2000, 1500 is middle/neutral
  data.Throttle = 1000;
  data.Yaw = 1500;
  data.Pitch = 1500;
  data.Roll = 1500;
  data.Aux1 = 1000;
  data.Aux2 = 1000;
  data.Aux3 = 1000;
  data.Aux4 = 1000;
  data.Aux5 = 1000;
  data.Aux6 = 1000;

  setPPMValuesFromData();
}

void setPPMValuesFromData(){
  PPM[0] = data.Throttle;
  PPM[1] = data.Yaw;
  PPM[2] = data.Pitch;
  PPM[3] = data.Roll;
  PPM[4] = data.Aux1;
  PPM[5] = data.Aux2;
  PPM[6] = data.Aux3;
  PPM[7] = data.Aux4;
  PPM[8] = data.Aux5;
  PPM[9] = data.Aux6;
}
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

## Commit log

2018-09-13 Updated EEPROM operation from "write" to "update" in some points to prevent burning out the EEPROM
    [AffoFly_Transmitter.ino]
2018-09-16 Initiated Receiver sketch
    Someone says use the Arduino timer to convert data into PPM is not acurate, also the FC has to convert PPM back to data then PWM to motor, it might not work properly. For this sketch I use it mainly testing the TX signal and planned make it use for simulator.
    [AffoFly_Receiver.ino]
2018-09-16 Shorten Frame Length from 27k to 24k to improve refresh rate
    This might cause compatibility issue on some flight controller, it is yet to discover.
    [AffoFly_Receiver.ino]
2018-09-19 Initiated MultiWii FC code with NRF24 RX
    This is based on MultiWii v2.41 and code from iForce2d for NRF24 RX.
    [config.h]
2018-09-22 Added RED LED for better indicating signal strength
    This is optional
2018-09-22 Enabled Buzzer and VBAT in MultiWii
    [config.h]
2018-09-22 Added Fritzing file and images for AffoFly_MultiWii
    This is not a real Fritzing file for circuit but only shows prototype board layout.
    [AffoFly_MultiWii.fzz]
2018-09-23 Prevent TX enter Trimming mode since Trimming function not been implemented yet and it messes up ROM data.
    [AffoFly_Transmitter.ino]
2018-09-23 Raised up RX battery minimum voltage and warning to protect my LiPo battery
    Since I am using a LiPo battery package so it is not a good idea to discharge it until 3.2v and then give warning. 3.2v was for 18650 (it can be 3.0 - 3.2). The BMS module cut off at 2.9 according to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
2018-09-23 Added prototype board layout for receiver
    [AffoFly_Receiver.fzz]
2018-09-23 Added receiver board layout suits for using as plane controller
2018-09-23 Created folder structure for Frames
2018-09-23 Updated Fritzing file for receiver
    [AffoFly_Receiver.fzz]
2018-09-30 Corrected some data types and proper way to pass char[]
    [AffoFly_Transmitter.ino]
2018-10-08 Implemented Trimming Function
    Trimming has been implemented, there are screen design improvement in plan.
    However, I just found buttons are triggered multiple times when press in Control mode, seem like something wrong with the program, not sure what is causing this. In Function mode, buttons are working correctly but not in Control mode. Will lodge an issue.
    [AffoFly_Transmitter.ino]
2018-10-08 Fixed buttons trigger multiple time in Control mode
    [AffoFly_Transmitter.ino]
